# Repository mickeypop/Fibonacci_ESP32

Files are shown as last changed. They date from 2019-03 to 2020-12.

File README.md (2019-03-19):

# Fibonacci Clock with ESP32 WiFi
ESP32 Atomic Fibonacci Clock with Android App and full Daylight Savings Time(DST) support

Unlike other Fibonacci Clocks, this is fully Atomic.  
Just set WiFi and a few presets with the first Arduino preset sketch to set preferances then compile the main sketch.

I also gave it minute accuracy, most Fibonacci Clocks can only show within 5 minutes.  4 Extra LEDs place the minutes that do not end in 0 or 5.

I added I2C LCD support for debugging but is not needed in use.

With mDNS support you can access it by web page or Android app as **fibonacci.local** once it is on your WiFi network.

Just choose your Time Zone and the DST rule that applies to you and the clock time is set.

Because I used the preferances library this will not work on the ESP8266 but with the Preferances replaced with file system and say JSON this could be adapted easily.

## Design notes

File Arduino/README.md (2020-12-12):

# Fibonacci_ESP32 code
ESP32 Atomic Fibonacci Clock with Android App and full Daylight Savings Time(DST) support

The code is fairly strait forward

 I load settings from preferences and get GMT time.  the TimeZone code corrects for your time zone.

setting time is simple

connect to the clock (fibonacci.local) pick your timezone then the timezon rule for your area.

thats it time is set

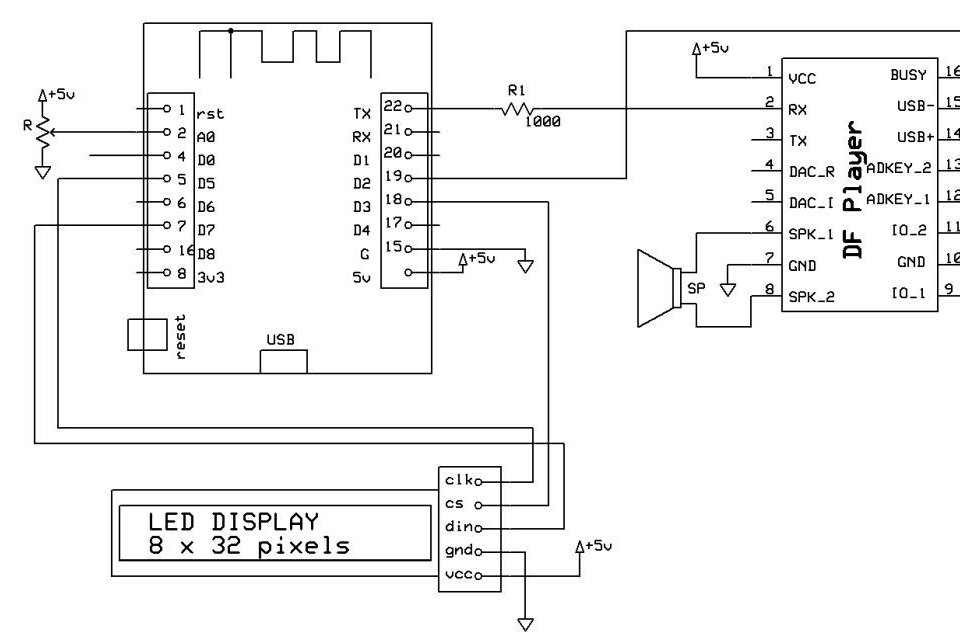
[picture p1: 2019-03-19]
Arduino/voices/voiceSCH.jpg

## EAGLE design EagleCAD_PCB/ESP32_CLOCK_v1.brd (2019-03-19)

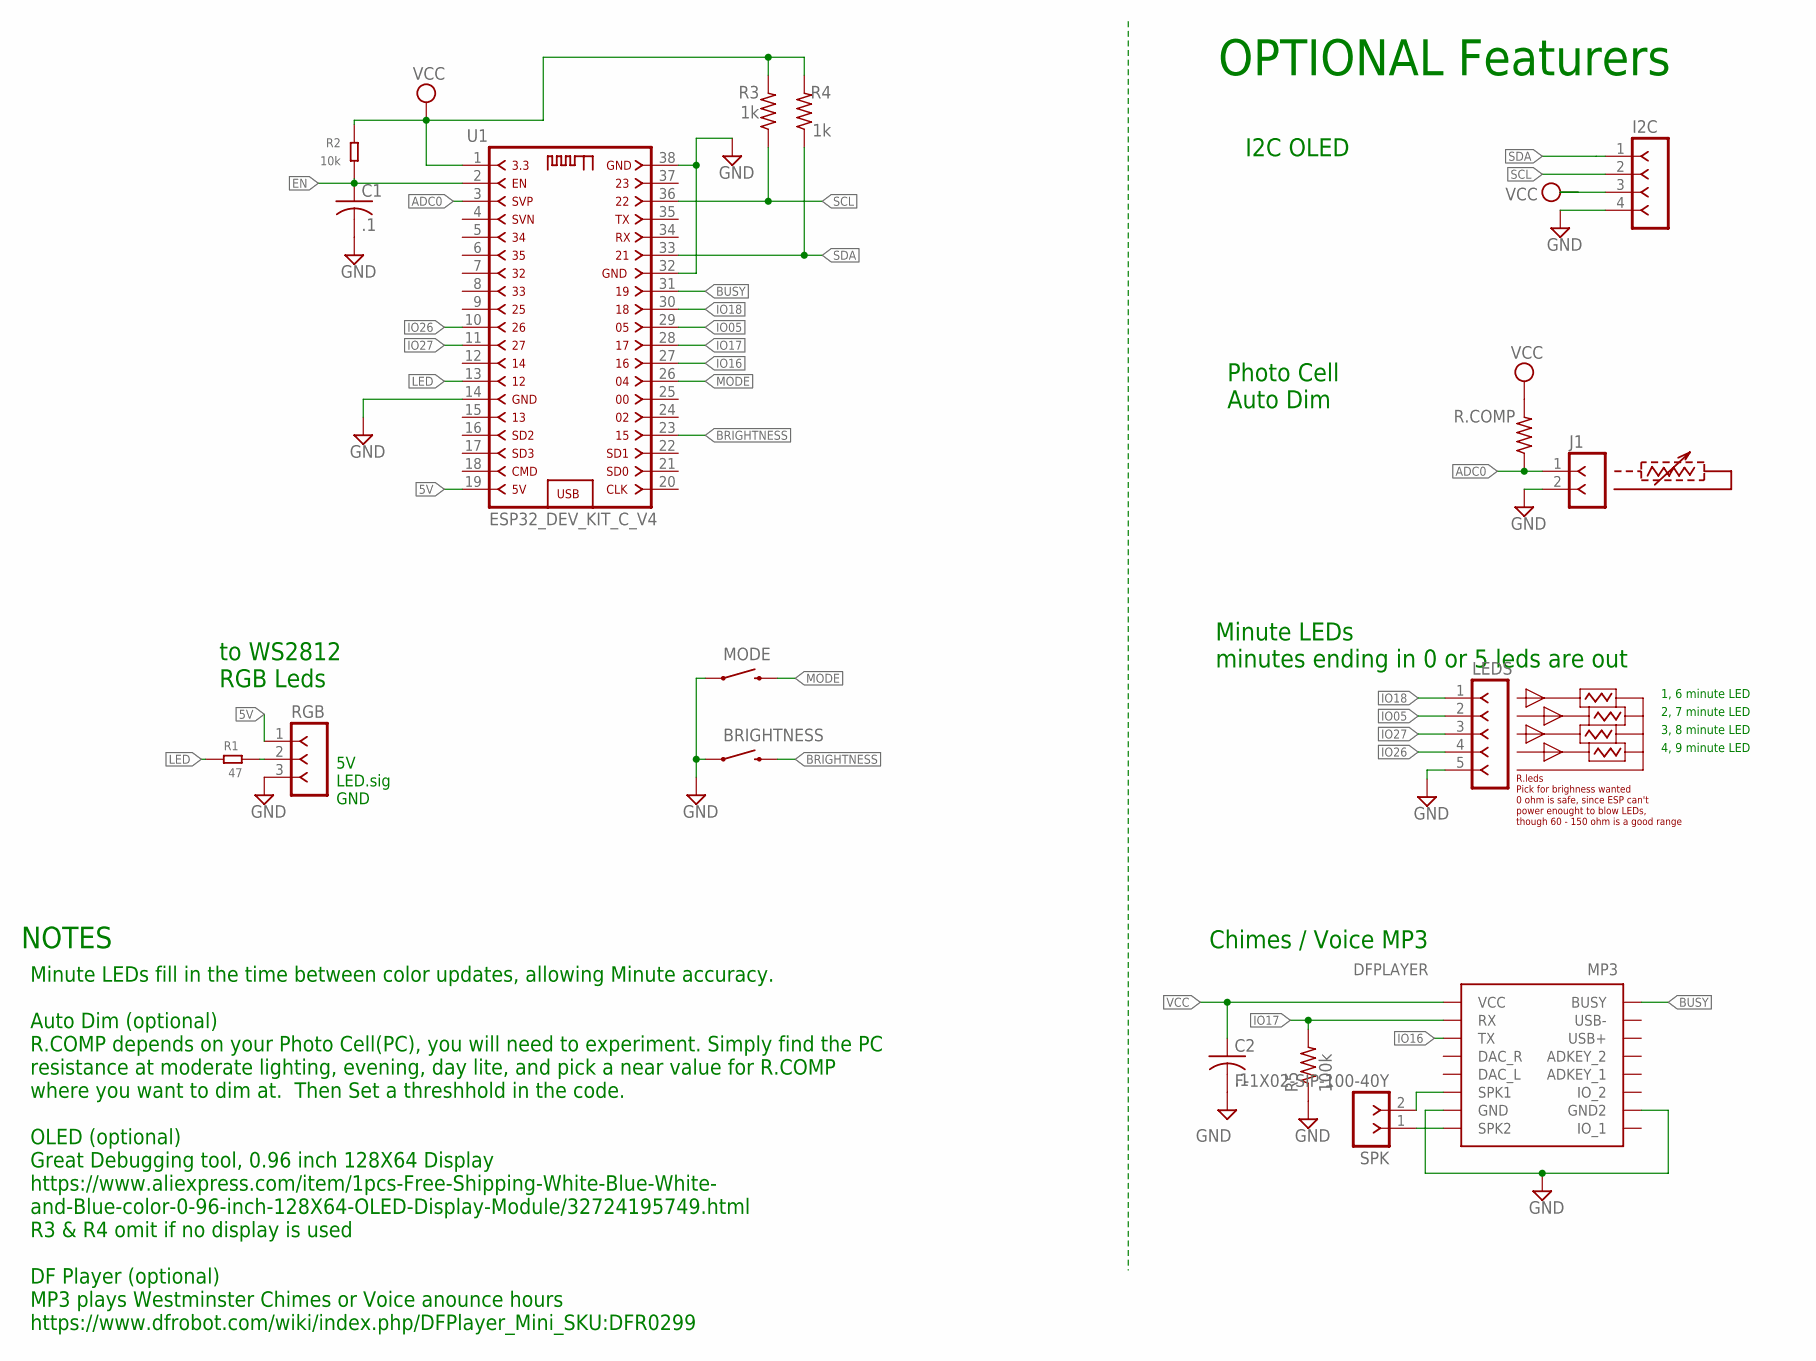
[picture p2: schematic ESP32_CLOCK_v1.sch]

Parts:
BRIGHTNESS: SWITCH-MOMENTARY-2SIDE_EZ; TACTILE-PTH-SIDEEZ
C1, C2: .1; C0805K
I2C: F-1X04-SIP-100-40Y; SIP-100-04-40Y
J1: F-1X02-SIP-100-40Y; SIP-100-02-40Y
LEDS: F-1X05-SIP-100-40Y; SIP-100-05-40Y
MODE: SWITCH-MOMENTARY-2SIDE_EZ; TACTILE-PTH-SIDEEZ
MP3: DFPLAYER
R1: 47; R0805
R2: 10k; R0805
R3, R4: 1k; M0805
R5: 100k; M0805
R.COMP: R-US_M0805; M0805
RGB: F-1X03-SIP-100-40Y; SIP-100-03-40Y
SPK: F-1X02-SIP-100-40Y; SIP-100-02-40Y
U1: ESP32_DEV_KIT_C_V4

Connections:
5V: RGB.1, U1.19
ADC0: J1.1, R.COMP.1, U1.3
BRIGHTNESS: BRIGHTNESS.2, U1.23
BUSY: MP3.BUSY, U1.31
EN: C1.1, R2.1, U1.2
GND: BRIGHTNESS.1, C1.2, C2.2, I2C.4, J1.2, LEDS.5, MODE.1, MP3.GND, MP3.GND2, R5.1, RGB.3, U1.14, U1.32, U1.38
IO05: LEDS.2, U1.29
IO16: MP3.TX, U1.27
IO17: MP3.RX, R5.2, U1.28
IO18: LEDS.1, U1.30
IO26: LEDS.4, U1.10
IO27: LEDS.3, U1.11
LED: R1.2, U1.13
MODE: MODE.2, U1.26
unnamed: MP3.SPK2, SPK.1
unnamed: MP3.SPK1, SPK.2
unnamed: R1.1, RGB.2
SCL: I2C.2, R3.1, U1.36
SDA: I2C.1, R4.1, U1.33
VCC: C2.1, I2C.3, MP3.VCC, R2.2, R3.2, R4.2, R.COMP.2, U1.1

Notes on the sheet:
to WS2812 RGB Leds
5V LED.sig GND
1, 6 minute LED
2, 7 minute LED
3, 8 minute LED
4, 9 minute LED
OPTIONAL Featurers
I2C OLED
Photo Cell Auto Dim
R.leds Pick for brighness wanted 0 ohm is safe, since ESP can't power enought to blow LEDs, though 60 - 150 ohm is a good range
Minute LEDs minutes ending in 0 or 5 leds are out
Chimes / Voice MP3
NOTES
Minute LEDs fill in the time between color updates, allowing Minute accuracy. Auto Dim (optional) R.COMP depends on your Photo Cell(PC), you will need to experiment. Simply find the PC resistance at moderate lighting, evening, day lite, and pick a near value for R.COMP where you want to dim at. The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

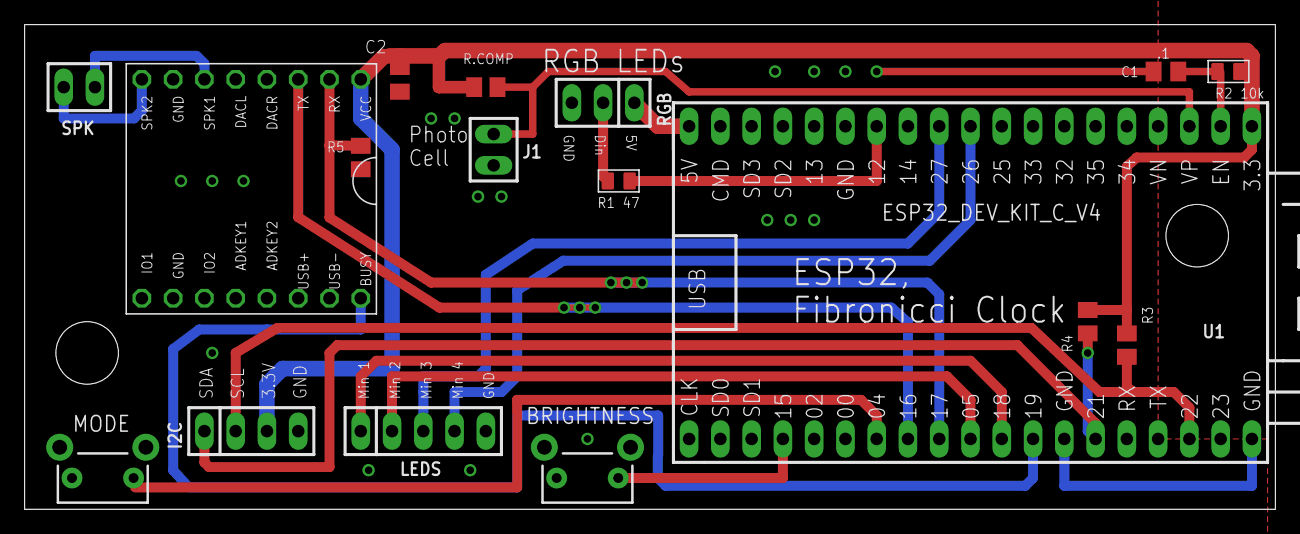
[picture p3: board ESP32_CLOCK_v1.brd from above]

Board: 2 copper layers, 101.6 x 39.4 mm, 17 parts (0 on the bottom side), 20 nets.

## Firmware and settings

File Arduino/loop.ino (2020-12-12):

void loop()
{
  if ( WiFi.status() == WL_CONNECTED )
  {
    // Main connected loop
   // analogValue = analogRead( ANALOG_PIN_0 ); // use for day/nite dimming
   // Serial.printf( "Pin value = %d \n", analogValue );

    checkNTPTimeValid();  // make sure NTP time is valid and/or fix
    clockUpdate();        // update local time from NTP
    handleDisplay();      // serial time & display routines

    ////  Fibonicci parts
    readButtons();
    handleButtons();

    resetButtonValues();    // Store buttons new values
    switch(mode)
    {
      case 0:
        displayCurrentTime();
        break;
      case 1:
        oldHours = 99;
        rainbowCycle(20);
        break;
      case 2:
        oldHours = 99;
        rainbow(20);
        break;
      case 3:
        oldHours = 99;
        displayErrorCode();        // Display error code
        break;
    }
    //// END Fibonicci parts

    #ifdef LIGHT_SENSOR
       setBrighDim();
    #endif
    delay(2000);
  }                 // END WiFi connected loop()
  else
  {                 // WiFi DOWN
    WFstatus = getWifiStatus( WFstatus );
    WiFi.begin( PrefSSID.c_str() , PrefPassword.c_str() );
    int WLcount = 0;
    while (WiFi.status() != WL_CONNECTED && WLcount < 200 )
    {
      delay( 100 );
      Serial.printf(".");

      if (UpCount >= 60)  // keep from scrolling sideways forever
      {
         UpCount = 0;
         Serial.printf("\n");
      }
      ++UpCount;
      ++WLcount;

        int temp = digitalRead(MODE_BUTTON);
      if (temp == LOW )
      {
        initSmartConfig();
      }
    }
    
   delay( 1000 );
  } // END WiFi down
} // END loop()

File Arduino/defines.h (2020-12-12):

// ENABLES comment out to disable some functions as desired
  #define F_DEBUG                 // comment out to stop many debug printouts
  //#define DEBUG_ESP_HTTP_SERVER // turns on Server debugging, comment out when done
  //#define DFPLAYER_ENABLED      // comment out if you do not have the player
  //#define OLED_DEBUG            // oled display for debugging turn off if not used
  #define LIGHT_SENSOR            // LDR sense room lights out to dim, comment out if not used
// END ENABLES

// RGB led Header setup
  #define LED_SIGNAL_PIN     32   // Digital IO pin connected to the NeoPixels.
  #define PIXEL_COUNT         9   // Number of LEDs
  uint8_t LED_BRIGHTNESS  = 128;  // place holder for dimming option 
  uint8_t BRIGHTNESS      = 128;  // defaut brightness level
  uint8_t BRIGHTNESS_HOLD = LED_BRIGHTNESS; // used to track changes
// END RGB led Header setup

// DIMMING vars
  int BRIGHTNESS_ON_OFF   =   1;  // 0 will go full OFF with light out / 1 DIM based on BRITE_DIVISOR
  int BRITE_THRESHOLD     = 1600; // set for typical lighting, determine based on Your LDR value
                                  // just connect OHM meter to LDR and measure in different lighting
                                  // my LDR was around 1.0K room lite, partial lite 15K, 1M covered
                                  //  so ADC room light aprox     300
                                  //         partial light aprox 1400
                                  //         dark light aprox    2300
  int  BRITE_DIVISOR     =   35;  // sets how much dimming, LED_BRIGHTNESS/BRITE_DIVISOR  will be over riddedn from stored settings
  bool BRITE_DIM = true;          // LEAVE THIS, dim state tracking vars 
  bool BRITE_LAST = true;         // LEAVE THIS, placeholder when dim
// END DIMMING vars


// marks minutes between color change
// minutes ending in 0 or 5 all stay off
  #define LED_1_MINUTE_PIN  15  // minutes 1 & 6
  #define LED_2_MINUTE_PIN  13  // minutes 2 & 7
  #define LED_3_MINUTE_PIN  12  // minutes 3 & 8
  #define LED_4_MINUTE_PIN  14  // minutes 4 & 9

// pins
  #define MODE_BUTTON       33
  #define BRIGHTNESS_BUTTON 25

// DFPLAYER
  #define SERIAL1_RXPIN     16  // Only GPIO 12 gives problems
  #define SERIAL1_TXPIN     17
  #define BUSY_PIN          19  // see if sound play is done

// adc on ADC_0 io36,     Used by auto dimming when light out at nite
  #define ANALOG_PIN_0      36

// from original clock
  #define DEBOUNCE_DELAY    10
  #define MAX_BUTTONS_INPUT 20
  #define MAX_MODES          3
  #define MAX_PALETTES      10
  #define TOTAL_PALETTES    10
  #define CLOCK_PIXELS       5

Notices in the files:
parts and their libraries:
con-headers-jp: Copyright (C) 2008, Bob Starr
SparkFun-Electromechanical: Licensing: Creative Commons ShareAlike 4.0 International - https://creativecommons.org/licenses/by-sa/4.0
